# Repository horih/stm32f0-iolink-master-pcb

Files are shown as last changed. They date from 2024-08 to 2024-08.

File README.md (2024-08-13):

# C104 IOLink-master-PCB
## 回路図PDF
[PDFファイル](iolink_pcb.pdf)
## パーツリスト
| 番号 | パーツ名 | 値 | その他 |
| :--- | :---: | :---: | :---: |
| C1,C6,C8,C11,C13,C18 | 0603 ceramic capacitor | 4.7uF| Vmax=3.3v|
| C19,C20,C21 | 0603 ceramic capacitor | 4.7uF | Vmax=30v |
| C2,C23 | 6.3x5.9 electrolytic capacitor | 47uF | Vmax=30v |
| C3 | 0603 ceramic capacitor | 22uF |　Vmax=3.3v |
| C4 | 0603 ceramic capacitor | 10uF | Vmax=5v | 
| C7,C9,C10,C12,C14,C17 | 0603 ceramic capacitor| 0.1uF |Vmax=5v |
| C15,C16 |0603 ceramic capacitor | 32pF |Vmax=3.3v|
| R1,R2 |0603 registor|60ohm|||
| R3,R4 |0603 registor|10kohm|||
| R5,R7,R11,R12 |0603 registor|10ohm|||
| R6,R8,R9,R10 | 0603 registor|0.2ohm|||
| R13,R17 | 0603 registor|4.7kohm|||
| R15,R16 | 0603 registor|0ohm|||
| D1, D2| 0603 LED|||
| IC1 | LTC2874IFE ||https://mou.sr/3X1CPJl|
| IC2 | AZ1117CH3.3TRG1||https://akizukidenshi.com/catalog/g/g116155/|
| IC3 | M78AR05-0.5||https://akizukidenshi.com/catalog/g/g107179/|
| Q1,Q2 | NDS9936 ||https://akizukidenshi.com/catalog/g/g116757/|
| U1 | STM32F091CCT6||https://mou.sr/4cnDoBN|
| U2 |MCP2562-H-SN||https://mou.sr/4dl9AXA|
| Y1 | Crystal| 8Mhz |https://akizukidenshi.com/catalog/g/g108667/|
| SW1| Push_Switch 6mm H4.3mm||https://akizukidenshi.com/catalog/g/g115969/|
|J1,J2,J4,J5,J6,J7,J8|2.54mm　terminal block||https://akizukidenshi.com/catalog/g/g114217/|

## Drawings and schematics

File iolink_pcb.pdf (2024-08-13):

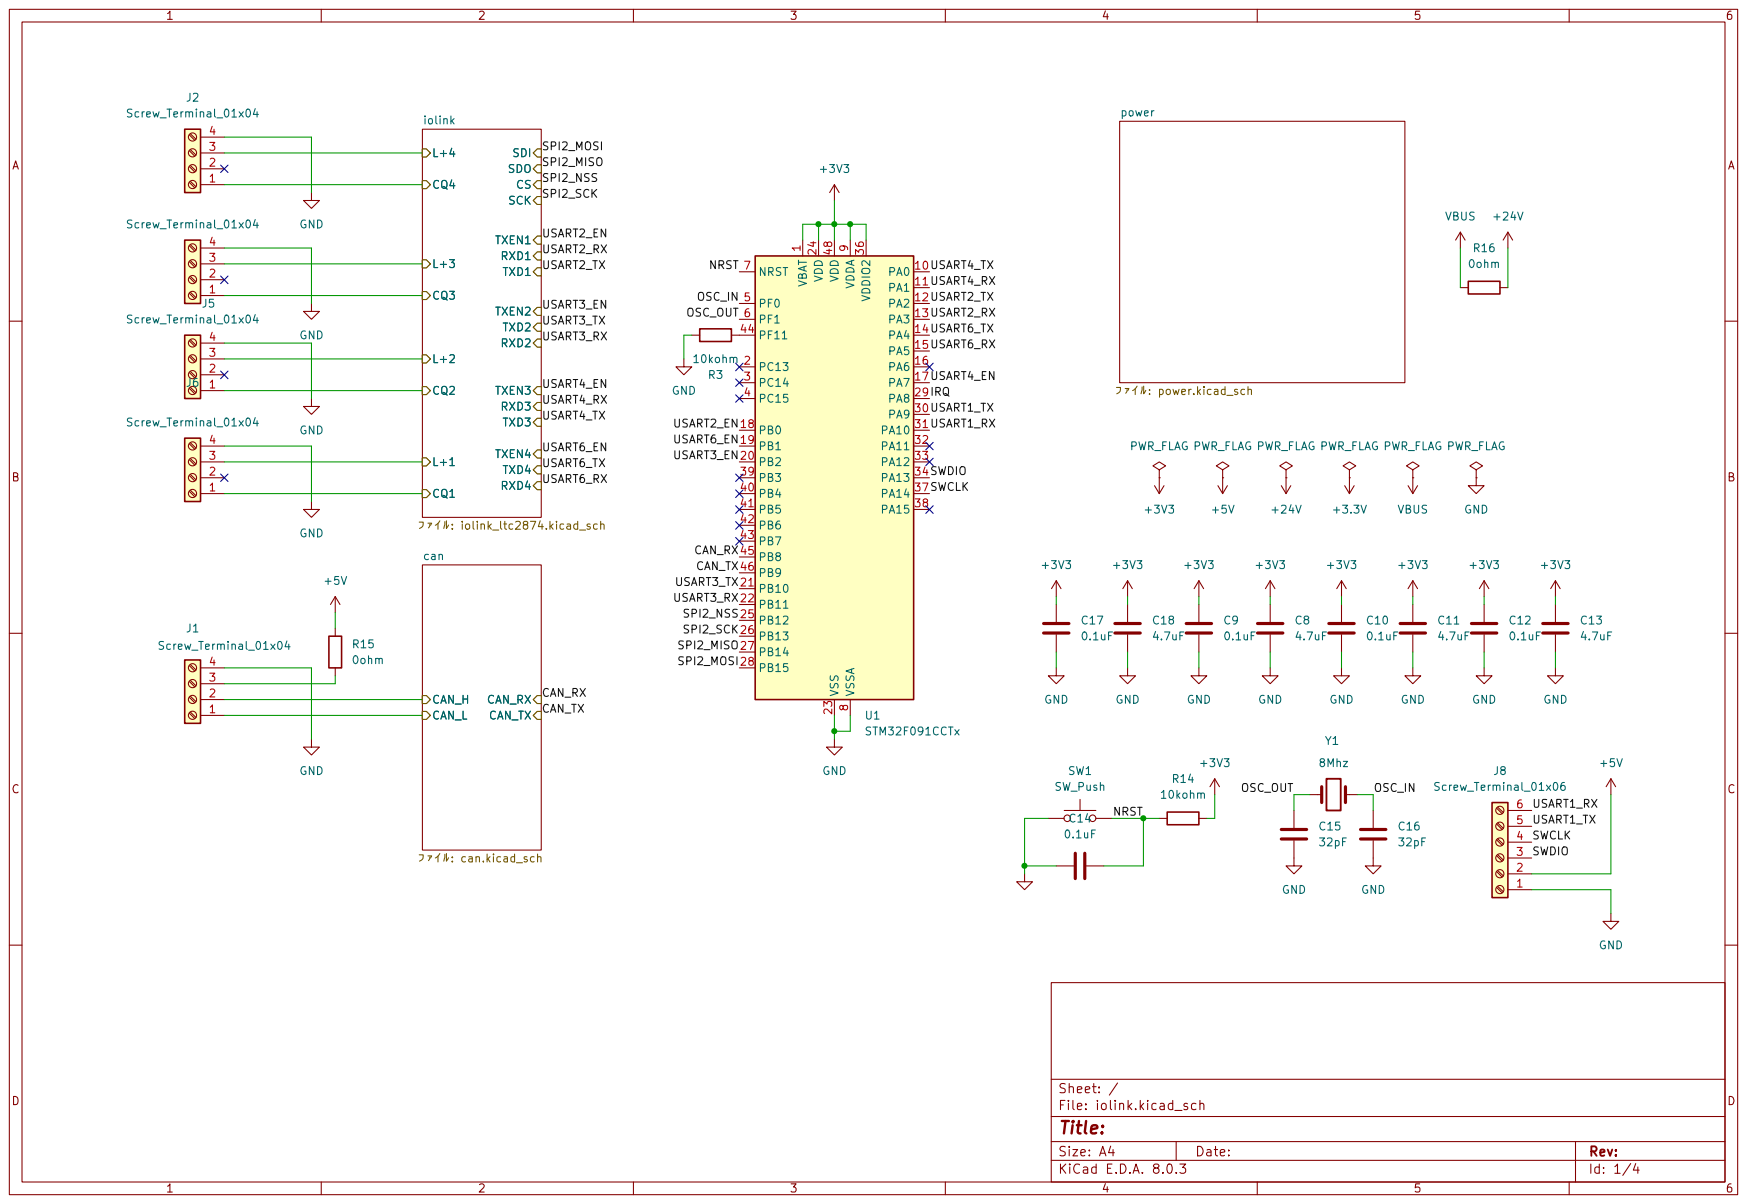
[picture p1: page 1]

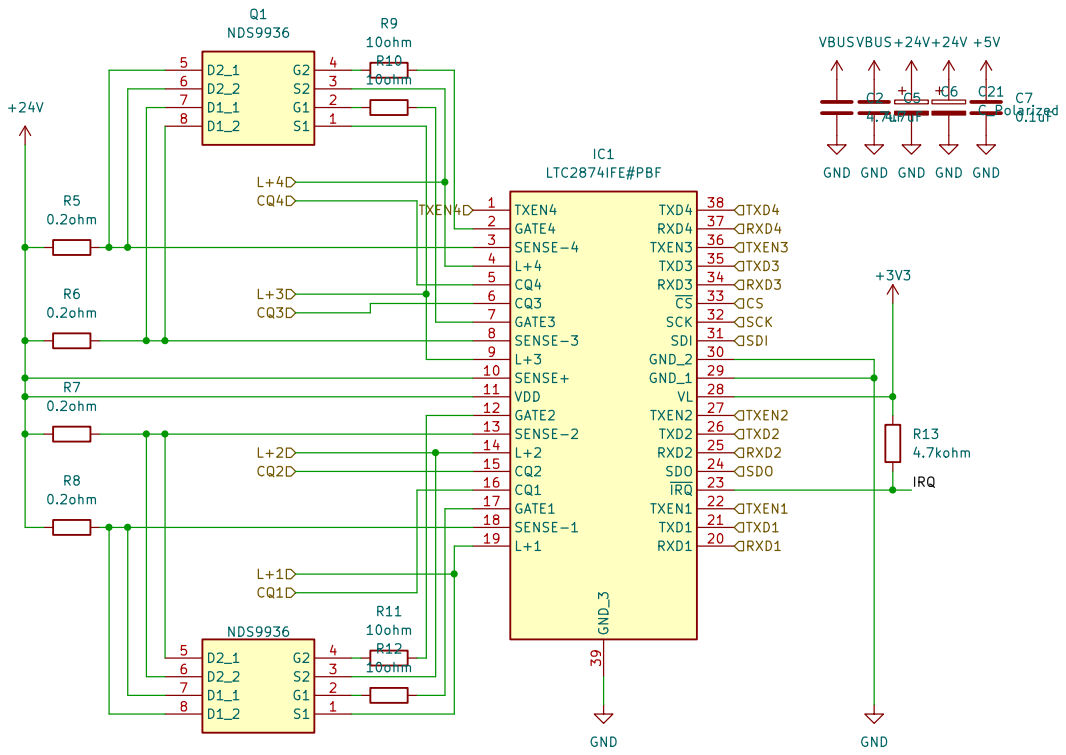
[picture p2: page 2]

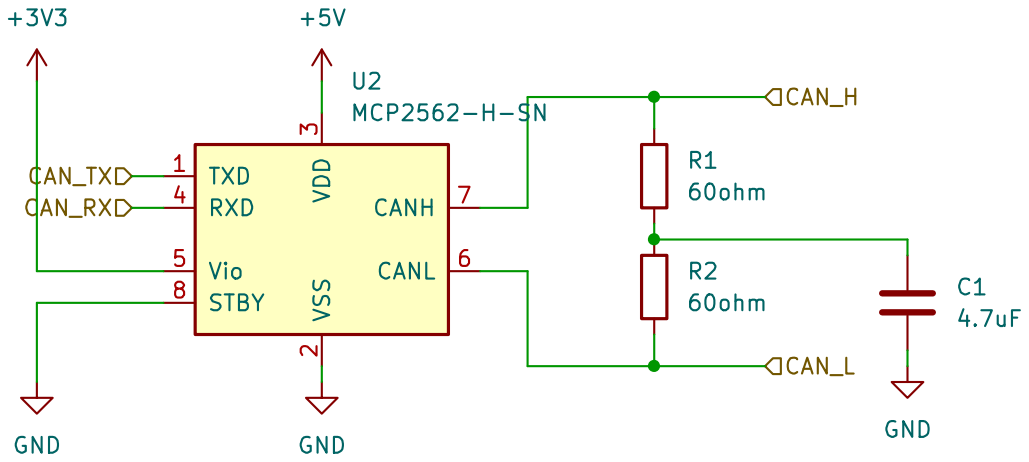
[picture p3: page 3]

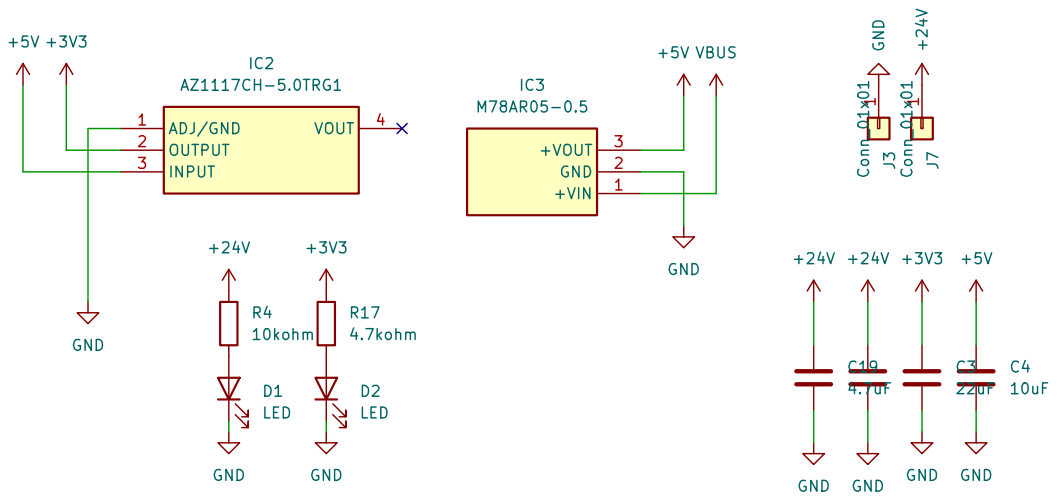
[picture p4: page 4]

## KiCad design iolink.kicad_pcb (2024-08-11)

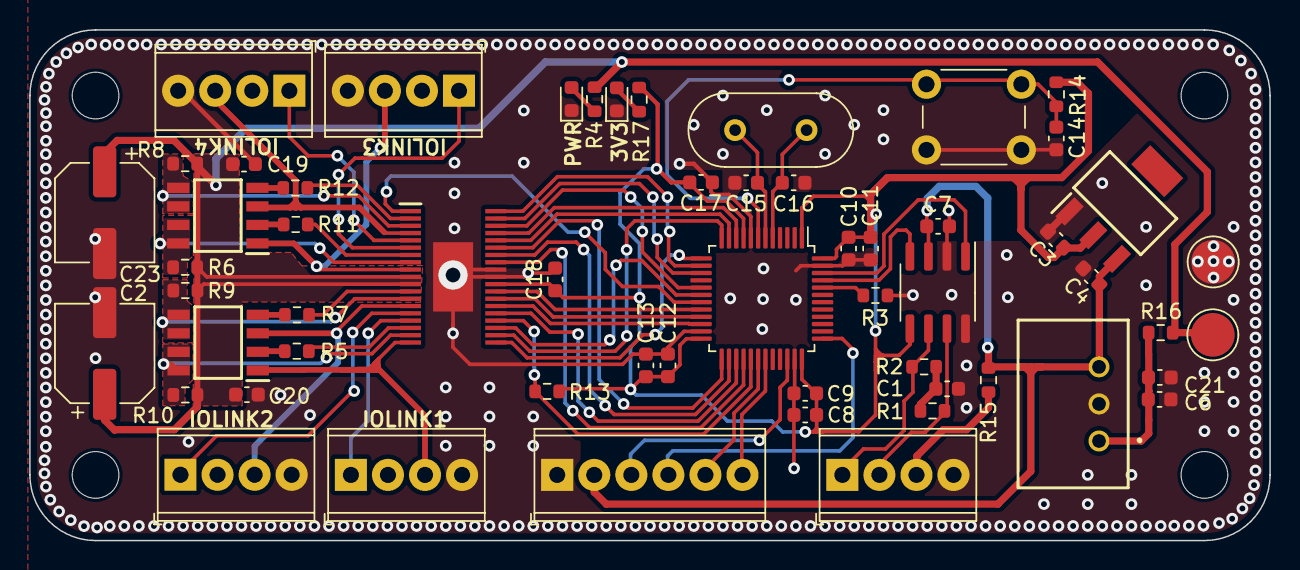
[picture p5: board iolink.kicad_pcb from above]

Board: 2 copper layers, 85.0 x 35.0 mm, 57 parts (0 on the bottom side), 58 nets.

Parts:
C1, C6, C8, C11, C13, C18, C19, C20, C21: 4.7uF; C_0603_1608Metric
C2, C23: C_Polarized; CP_Elec_6.3x5.9
C3: 22uF; C_0603_1608Metric
C4: 10uF; C_0603_1608Metric
C7, C9, C10, C12, C14, C17: 0.1uF; C_0603_1608Metric
C15, C16: 32pF; C_0603_1608Metric
D1, D2: LED; LED_0603_1608Metric
IC1: LTC2874IFE#PBF; SOP50P640X120-39N
IC2: AZ1117CH-5.0TRG1; SOT230P700X180-4N
IC3: M78AR05-0.5; M78AR05
J1, J4, J5, J6, J7: Screw_Terminal_01x04; TerminalBlock_Phoenix_MPT-0,5-4-2.54_1x04_P2.54mm_Horizontal
J3, J9: Conn_01x01; TestPoint_Pad_D3.0mm
J8: Screw_Terminal_01x06; TerminalBlock_Phoenix_MPT-0,5-6-2.54_1x06_P2.54mm_Horizontal
Q1, Q2: NDS9936; SOIC127P600X175-8N
R1, R2: 60ohm; R_0603_1608Metric
R3, R14: 10kohm; R_0603_1608Metric
R4: 10k; R_0603_1608Metric
R5, R7, R11, R12: 10ohm; R_0603_1608Metric
R6, R8, R9, R10: 0.2ohm; R_0603_1608Metric
R13: 4.7kohm; R_0603_1608Metric
R15, R16: 0; R_0603_1608Metric
R17: 4.7k; R_0603_1608Metric
SW1: SW_Push; SW_PUSH_6mm_H4.3mm
U1: STM32F091CCTx; LQFP-48_7x7mm_P0.5mm
U2: MCP2562-H-SN; SOIC-8_3.9x4.9mm_P1.27mm
Y1: 8Mhz; Crystal_HC18-U_Vertical

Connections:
+3V3: C3.1, C8.1, C9.1, C10.1, C11.1, C12.1, C13.1, C17.1, C18.1, IC1.28 (VL), IC2.2 (OUTPUT), R13.1, R14.2, R17.1, U1.1 (VBAT), U1.9 (VDDA), U1.24 (VDD), U1.36 (VDDIO2), U1.48 (VDD), U2.5 (Vio)
+5V: C4.1, C7.1, IC2.3 (INPUT), IC3.3 (+VOUT), J8.2, R15.1, U2.3 (VDD)
+24V: C2.1, C19.1, C20.1, C23.1, IC1.10 (SENSE+), IC1.11 (VDD), J3.1, R4.1, R6.2, R8.2, R9.2, R10.2, R16.2
/CAN_H: J1.2, R1.1, U2.7 (CANH)
/CAN_L: J1.1, R2.2, U2.6 (CANL)
/CAN_RX: U1.45 (PB8), U2.4 (RXD)
/CAN_TX: U1.46 (PB9), U2.1 (TXD)
/IRQ: IC1.23 (~IRQ), R13.2, U1.29 (PA8)
/NRST: C14.2, R14.1, SW1.2, U1.7 (NRST)
/OSC_IN: C16.1, U1.5 (PF0), Y1.2
/OSC_OUT: C15.1, U1.6 (PF1), Y1.1
/SPI2_MISO: IC1.24 (SDO), U1.27 (PB14)
/SPI2_MOSI: IC1.31 (SDI), U1.28 (PB15)
/SPI2_NSS: IC1.33 (~CS), U1.25 (PB12)
/SPI2_SCK: IC1.32 (SCK), U1.26 (PB13)
/SWCLK: J8.4, U1.37 (PA14)
/SWDIO: J8.3, U1.34 (PA13)
/USART1_RX: J8.6, U1.31 (PA10)
/USART1_TX: J8.5, U1.30 (PA9)
/USART2_EN: IC1.22 (TXEN1), U1.18 (PB0)
/USART2_RX: IC1.20 (RXD1), U1.13 (PA3)
/USART2_TX: IC1.21 (TXD1), U1.12 (PA2)
/USART3_EN: IC1.27 (TXEN2), U1.20 (PB2)
/USART3_RX: IC1.25 (RXD2), U1.22 (PB11)
/USART3_TX: IC1.26 (TXD2), U1.21 (PB10)
/USART4_EN: IC1.36 (TXEN3), U1.17 (PA7)
/USART4_RX: IC1.34 (RXD3), U1.11 (PA1)
/USART4_TX: IC1.35 (TXD3), U1.10 (PA0)
/USART6_EN: IC1.1 (TXEN4), U1.19 (PB1)
/USART6_RX: IC1.37 (RXD4), U1.15 (PA5)
/USART6_TX: IC1.38 (TXD4), U1.14 (PA4)
GND: C1.1, C2.2, C3.2, C4.2, C6.2, C7.2, C8.2, C9.2, C10.2, C11.2, C12.2, C13.2, C14.1, C15.2, C16.2, C17.2, C18.2, C19.2, C20.2, C21.2, C23.2, D1.1 (K), D2.1 (K), IC1.29 (GND_1), IC1.30 (GND_2), IC1.39 (GND_3), IC2.1 (ADJ/GND), IC3.2 (GND), J1.4, J4.4, J5.4, J6.4, J7.4, J8.1, J9.1, R3.2, SW1.1, U1.8 (VSSA), U1.23 (VSS), U1.35 (VSS), U1.47 (VSS), U2.2 (VSS), U2.8 (STBY)
unnamed: C1.2, R1.2, R2.1
unnamed: D1.2 (A), R4.2
unnamed: D2.2 (A), R17.2
unnamed: IC1.16 (CQ1), J5.1
unnamed: IC1.15 (CQ2), J4.1
unnamed: IC1.6 (CQ3), J6.1
unnamed: IC1.5 (CQ4), J7.1
unnamed: IC1.17 (GATE1), R5.2
unnamed: IC1.12 (GATE2), R7.2
unnamed: IC1.7 (GATE3), R11.2
unnamed: IC1.2 (GATE4), R12.2
unnamed: IC1.19 (L+1), J5.3, Q1.1 (S1)
unnamed: IC1.14 (L+2), J4.3, Q1.3 (S2)
unnamed: IC1.9 (L+3), J6.3, Q2.1 (S1)
unnamed: IC1.4 (L+4), J7.3, Q2.3 (S2)
unnamed: IC1.18 (SENSE-1), Q1.7 (D1_1), Q1.8 (D1_2), R10.1
unnamed: IC1.13 (SENSE-2), Q1.5 (D2_1), Q1.6 (D2_2), R9.1
unnamed: IC1.8 (SENSE-3), Q2.7 (D1_1), Q2.8 (D1_2), R6.1
unnamed: IC1.3 (SENSE-4), Q2.5 (D2_1), Q2.6 (D2_2), R8.1
unnamed: J1.3, R15.2
unnamed: Q1.2 (G1), R5.1
unnamed: Q1.4 (G2), R7.1
unnamed: Q2.2 (G1), R11.1
unnamed: Q2.4 (G2), R12.1
unnamed: R3.1, U1.44 (PF11)
VBUS: C6.1, C21.1, IC3.1 (+VIN), R16.1
